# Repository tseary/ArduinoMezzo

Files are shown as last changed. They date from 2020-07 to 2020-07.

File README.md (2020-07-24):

# ArduinoMezzo
Arduino Mezzo is a functional half-scale replica of the Arduino Uno.<p/> 
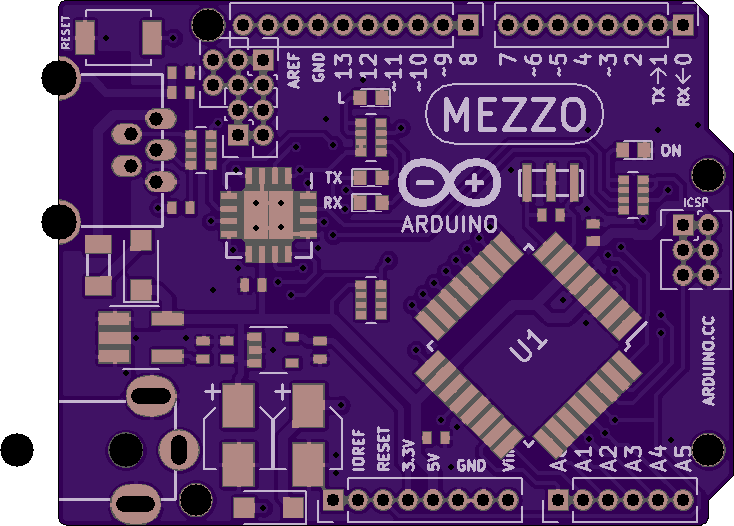
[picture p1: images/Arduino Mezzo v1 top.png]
My image
<p/>

I created this project as a novelty and as an exercise in miniaturization. As much as possible, the components
are 50% of the size of the components on the real Uno. The pin headers are all 50 mil pitch instead of 100 mil, and
the LEDs are 0402's instead of 0805's. Some parts differ because a half-scale version doesn't exist - the
USB connector is a mini-B instead of B type, and the power jack is has a 2.5 mm OD instead of the standard 5.5 mm.<p/>

Functional differences include a simplified power supply, and a different chip entirely for the USB-serial bridge.
The real Uno power supply has comparators and MOSFETs to select between USB and battery power. The Mezzo simply
combines the two sources using schottky diodes. To program the Mezzo, you have to manually press the reset button
since there is no DTR reset as in the Uno.<p/>

I hope that this project amuses you as much as it did me. If you make your own Mezzo I'd love to see it!<p/>

Disclaimer: This is not an official Arduino product and I am not affiliated with Arduino in any way.
This design is made available for anyone to use for any purpose, at their own risk.

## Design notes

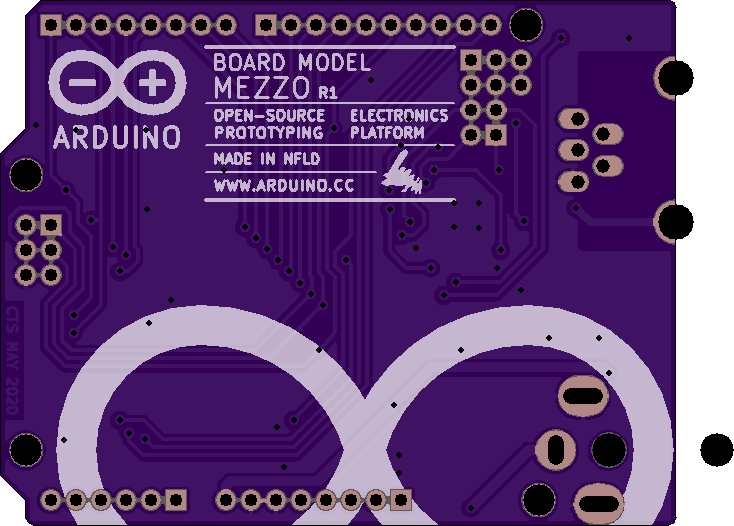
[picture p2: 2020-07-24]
images/Arduino Mezzo v1 bottom.png

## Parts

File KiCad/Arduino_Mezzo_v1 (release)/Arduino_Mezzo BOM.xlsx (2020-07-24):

Reference | Value | Footprint | Digikey Part # | In Cart | Datasheet
SW1 | RESET | Buttons_Switches_SMD:SW_SPST_B3U-1000P | SW1020CT-ND‎ | 3 | ~
C1 | 10uF | Capacitors_SMD:CP_Elec_3x5.3 | 338-1793-1-ND‎ | 6 | AVE106M16A12T-F
C2 | 10uF | Capacitors_SMD:CP_Elec_3x5.3 | 338-1793-1-ND‎ |  | AVE106M16A12T-F
F1 | 500mA | Custom_Library:0805 | 507-2075-1-ND‎ | 3 | 0ZCK0050AF2E
J6 | VIN | Custom_Library:Conn_DC_Jack_2.35mm_TH | 732-5920-ND‎ | 3 | ~
J5 | USB_B_Mini | Custom_Library:Conn_USB_Mini-B_TH | 54-00019T-ND‎ | 3 | 54-00019
H1 | 2020-01-16 | Custom_Library:M2_Isolated | N/A | 0 | ~
H2 | 2020-01-16 | Custom_Library:M2_Isolated | N/A |  | ~
H3 | 2020-01-16 | Custom_Library:M2_Isolated | N/A |  | ~
H4 | 2020-01-16 | Custom_Library:M2_Isolated | N/A |  | ~
Y1 | 16MHz | Custom_Library:XTAL_SMD_CSTNE | 490-17948-1-ND‎ | 3 | CSTNE16M0V530000R0
D1 | RB560VM | Diodes_SMD:D_SOD-323_HandSoldering | 1727-8169-1-ND‎ | 6 | ~
D8 | RB560VM | Diodes_SMD:D_SOD-323_HandSoldering | 1727-8169-1-ND‎ |  | ~
U2 | FT230XQ | Housings_DFN_QFN:QFN-16-1EP_4x4mm_Pitch0.65mm | 768-1130-1-ND‎ | 3 | https://www.ftdichip.com/Support/Documents/DataSheets/ICs/DS_FT230X.pdf
U1 | ATmega328P-AU | Housings_QFP:TQFP-32_7x7mm_Pitch0.8mm | ATMEGA328P-AU-ND | 3 | http://ww1.microchip.com/downloads/en/DeviceDoc/ATmega328_P%20AVR%20MCU%20with%20picoPower%20Technology%20Data%20Sheet%2040001984A.pdf
D5 | ON | LEDs:LED_0402 | 732-11992-1-ND‎ | 10 | ~
D7 | L | LEDs:LED_0402 | 732-11993-1-ND‎ | 10 | ~
D4 | RX | LEDs:LED_0402 | 732-11993-1-ND‎ |  | ~
D3 | TX | LEDs:LED_0402 | 732-11993-1-ND‎ |  | ~
J2 | AD | Pin_Headers:Pin_Header_Straight_1x06_Pitch1.27mm | S9008E-06-ND‎ | 3 | ~
J4 | IOL | Pin_Headers:Pin_Header_Straight_1x08_Pitch1.27mm | S9008E-08-ND‎ | 6 | ~
J1 | POWER | Pin_Headers:Pin_Header_Straight_1x08_Pitch1.27mm | S9008E-08-ND‎ |  | ~
J3 | IOH | Pin_Headers:Pin_Header_Straight_1x10_Pitch1.27mm | S9008E-10-ND‎ | 3 | ~
J9 | EXTRA | Pin_Headers:Pin_Header_Straight_2x02_Pitch1.27mm | N/A | 0 | ~
J8 | DUMMY | Pin_Headers:Pin_Header_Straight_2x03_Pitch1.27mm | S9015E-03-ND‎ | 6 | ~
J7 | ICSP | Pin_Headers:Pin_Header_Straight_2x03_Pitch1.27mm | S9015E-03-ND‎ |  | ~
C3 | 0.1uF | Resistors_SMD:R_0402_NoSilk | 732-7532-1-ND | 15 | ~
C4 | 0.1uF | Resistors_SMD:R_0402_NoSilk | 732-7532-1-ND |  | ~
C5 | 0.1uF | Resistors_SMD:R_0402_NoSilk | 732-7532-1-ND |  | ~
C6 | 0.1uF | Resistors_SMD:R_0402_NoSilk | 732-7532-1-ND |  | ~
R2 | 1M | Resistors_SMD:R_0402_NoSilk | RMCF0402FT1M00CT-ND | 10 | ~
C7 | 1uF | Resistors_SMD:R_0402_NoSilk | 399-4873-1-ND‎ | 10 | C0402C105K9PACTU
L1 | BLM21 | Resistors_SMD:R_0402_NoSilk | 445-2981-1-ND‎ | 3 | MPZ1005S121CT000
C8 | 470pF | Resistors_SMD:R_0402_NoSilk | 732-7554-1-ND‎ | 10 | ~
D2 | PGB1 | Resistors_SMD:R_0402_NoSilk | F2862CT-ND‎ | 6 | ~
D6 | PGB1 | Resistors_SMD:R_0402_NoSilk | F2862CT-ND‎ |  | ~
RN3 | 22 | Resistors_SMD:R_Array_Convex_4x0402 | 741X083220JPCT-ND | 3
RN1 | 10k | Resistors_SMD:R_Array_Convex_4x0402 | 741X083103JPCT-ND | 3
RN2 | 1k | Resistors_SMD:R_Array_Convex_4x0402 | 741X083102JPCT-ND | 6
RN4 | 1k | Resistors_SMD:R_Array_Convex_4x0402 | 741X083102JPCT-ND
U3 | MIC5219-5.0YM5 | TO_SOT_Packages_SMD:SOT-23-5_HandSoldering | 576-2770-1-ND‎ | 3 | http://ww1.microchip.com/downloads/en/DeviceDoc/MIC5219-500mA-Peak-Output-LDO-Regulator-DS20006021A.pdf
U4 | MIC5365-3.3YC5 | TO_SOT_Packages_SMD:SOT-353_SC-70-5 | 576-3193-1-ND‎ | 3 | http://ww1.microchip.com/downloads/en/DeviceDoc/mic5365.pdf

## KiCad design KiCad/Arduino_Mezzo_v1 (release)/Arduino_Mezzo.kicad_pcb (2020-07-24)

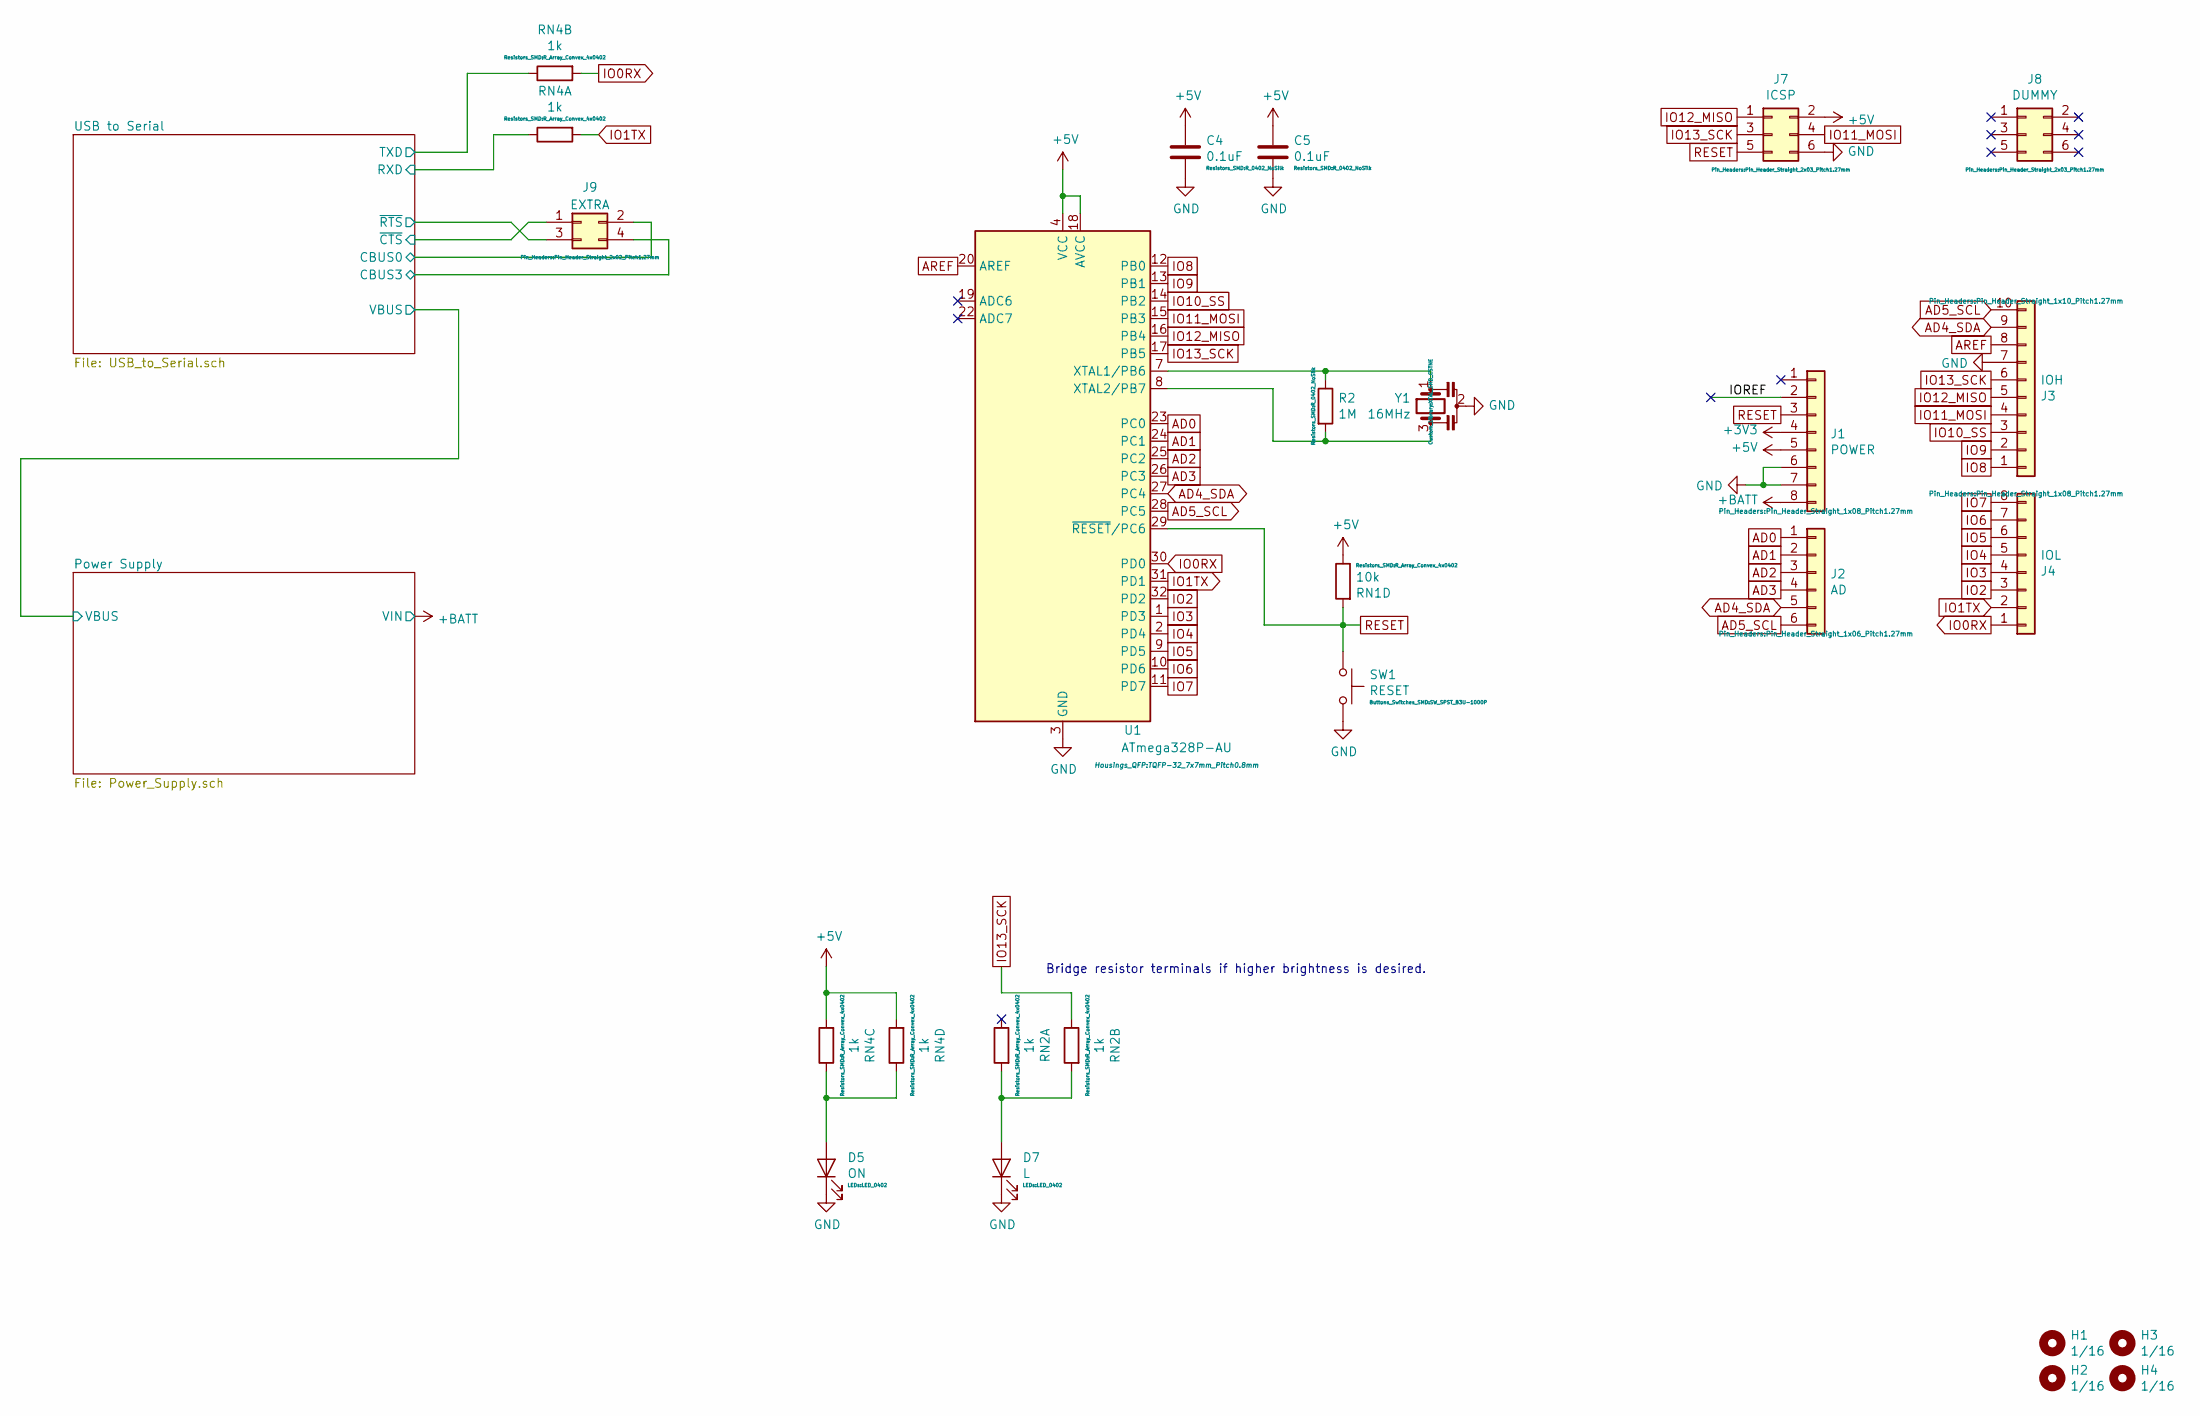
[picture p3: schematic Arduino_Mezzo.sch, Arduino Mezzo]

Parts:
C4, C5: 0.1uF; R_0402_NoSilk
D5: ON; LED_0402
D7: L; LED_0402
H1, H2, H3, H4: 1/16; M2_Isolated
J1: POWER; Pin_Header_Straight_1x08_Pitch1.27mm
J2: AD; Pin_Header_Straight_1x06_Pitch1.27mm
J3: IOH; Pin_Header_Straight_1x10_Pitch1.27mm
J4: IOL; Pin_Header_Straight_1x08_Pitch1.27mm
J7: ICSP; Pin_Header_Straight_2x03_Pitch1.27mm
J8: DUMMY; Pin_Header_Straight_2x03_Pitch1.27mm
J9: EXTRA; Pin_Header_Straight_2x02_Pitch1.27mm
R2: 1M; R_0402_NoSilk
RN1: 10k; R_Array_Convex_4x0402
RN2, RN4: 1k; R_Array_Convex_4x0402
SW1: RESET; SW_SPST_B3U-1000P
U1: ATmega328P-AU; TQFP-32_7x7mm_Pitch0.8mm
Y1: 16MHz; XTAL_SMD_CSTNE

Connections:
+3V3: J1.4; also elsewhere on the board
+5V: C4.1, C5.1, J1.5, J7.2, RN1.5, RN4.3, RN4.4, U1.4 (VCC), U1.6 (VCC), U1.18 (AVCC); also elsewhere on the board
+BATT: J1.8; also elsewhere on the board
/IOREF: J1.2
/USB to Serial/CBUS0: J9.2; also elsewhere on the board
/USB to Serial/CBUS3: J9.4; also elsewhere on the board
/USB to Serial/RXD: RN4.8; also elsewhere on the board
/USB to Serial/TXD: RN4.7; also elsewhere on the board
/USB to Serial/~CTS: J9.1; also elsewhere on the board
/USB to Serial/~RTS: J9.3; also elsewhere on the board
AD0: J2.1, U1.23 (PC0)
AD1: J2.2, U1.24 (PC1)
AD2: J2.3, U1.25 (PC2)
AD3: J2.4, U1.26 (PC3)
AD4_SDA: J2.5, J3.9, U1.27 (PC4)
AD5_SCL: J2.6, J3.10, U1.28 (PC5)
AREF: J3.8, U1.20 (AREF)
GND: C4.2, C5.2, D5.1 (K), D7.1 (K), J1.6, J1.7, J3.7, J7.6, SW1.2, U1.3 (GND), U1.5 (GND), U1.21 (GND), Y1.2; also elsewhere on the board
IO0RX: J4.1, RN4.2, U1.30 (PD0)
IO1TX: J4.2, RN4.1, U1.31 (PD1)
IO2: J4.3, U1.32 (PD2)
IO3: J4.4, U1.1 (PD3)
IO4: J4.5, U1.2 (PD4)
IO5: J4.6, U1.9 (PD5)
IO6: J4.7, U1.10 (PD6)
IO7: J4.8, U1.11 (PD7)
IO8: J3.1, U1.12 (PB0)
IO9: J3.2, U1.13 (PB1)
IO10_SS: J3.3, U1.14 (PB2)
IO11_MOSI: J3.4, J7.4, U1.15 (PB3)
IO12_MISO: J3.5, J7.1, U1.16 (PB4)
IO13_SCK: J3.6, J7.3, RN2.7, U1.17 (PB5)
unnamed: D5.2 (A), RN4.5, RN4.6
unnamed: D7.2 (A), RN2.1, RN2.2
unnamed: R2.1, U1.7 (XTAL1/PB6), Y1.1
unnamed: R2.2, U1.8 (XTAL2/PB7), Y1.3
RESET: J1.3, J7.5, RN1.4, SW1.1, U1.29 (~RESET~/PC6)

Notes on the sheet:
Bridge resistor terminals if higher brightness is desired.

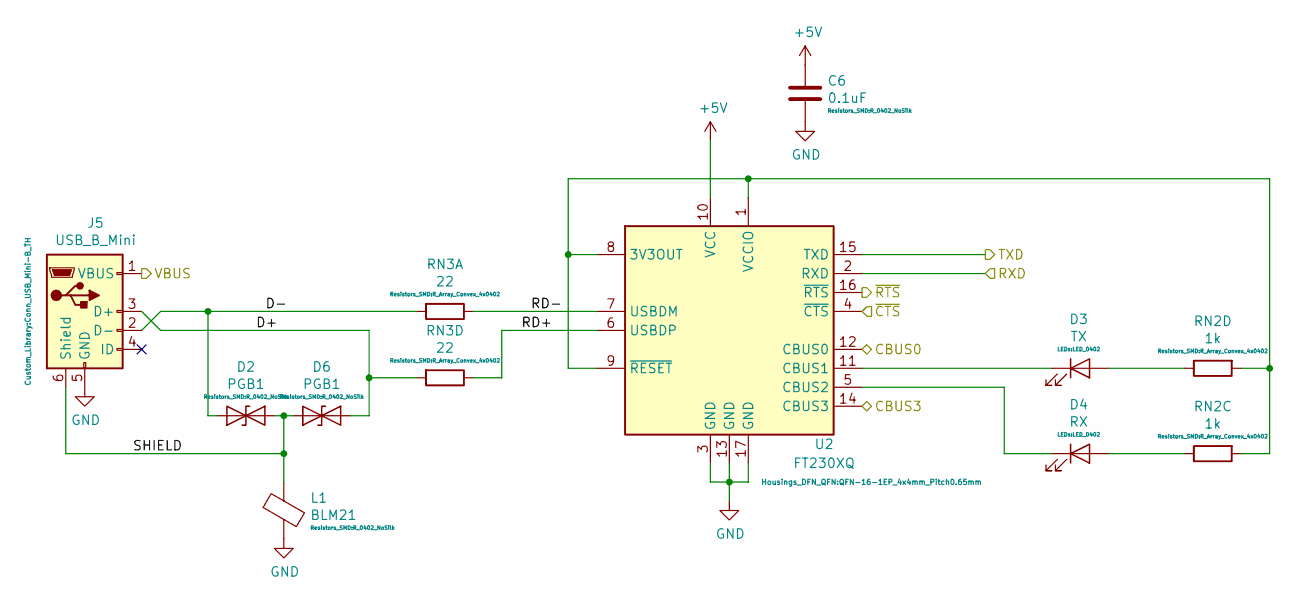
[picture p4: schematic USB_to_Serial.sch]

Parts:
C6: 0.1uF; R_0402_NoSilk
D2, D6: PGB1; R_0402_NoSilk
D3: TX; LED_0402
D4: RX; LED_0402
J5: USB_B_Mini; Conn_USB_Mini-B_TH
L1: BLM21; R_0402_NoSilk
RN2: 1k; R_Array_Convex_4x0402
RN3: 22; R_Array_Convex_4x0402
U2: FT230XQ; QFN-16-1EP_4x4mm_Pitch0.65mm

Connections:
+5V: C6.1, U2.10 (VCC); also elsewhere on the board
/Power Supply/VBUS: J5.1 (VBUS); also elsewhere on the board
/USB to Serial/CBUS0: U2.12 (CBUS0); also elsewhere on the board
/USB to Serial/CBUS3: U2.14 (CBUS3); also elsewhere on the board
/USB to Serial/D+: D6.2 (A2), J5.3 (D+), RN3.4
/USB to Serial/D-: D2.1 (A1), J5.2 (D-), RN3.1
/USB to Serial/RD+: RN3.5, U2.6 (USBDP)
/USB to Serial/RD-: RN3.8, U2.7 (USBDM)
/USB to Serial/RXD: U2.2 (RXD); also elsewhere on the board
/USB to Serial/SHIELD: D2.2 (A2), D6.1 (A1), J5.6 (Shield), L1.1
/USB to Serial/TXD: U2.15 (TXD); also elsewhere on the board
/USB to Serial/~CTS: U2.4 (~CTS); also elsewhere on the board
/USB to Serial/~RTS: U2.16 (~RTS); also elsewhere on the board
GND: C6.2, J5.5 (GND), L1.2, U2.3 (GND), U2.13 (GND), U2.17 (GND); also elsewhere on the board
unnamed: D3.1 (K), U2.11 (CBUS1)
unnamed: D3.2 (A), RN2.5
unnamed: D4.1 (K), U2.5 (CBUS2)
unnamed: D4.2 (A), RN2.6
unnamed: RN2.3, RN2.4, U2.1 (VCCIO), U2.8 (3V3OUT), U2.9 (~RESET)

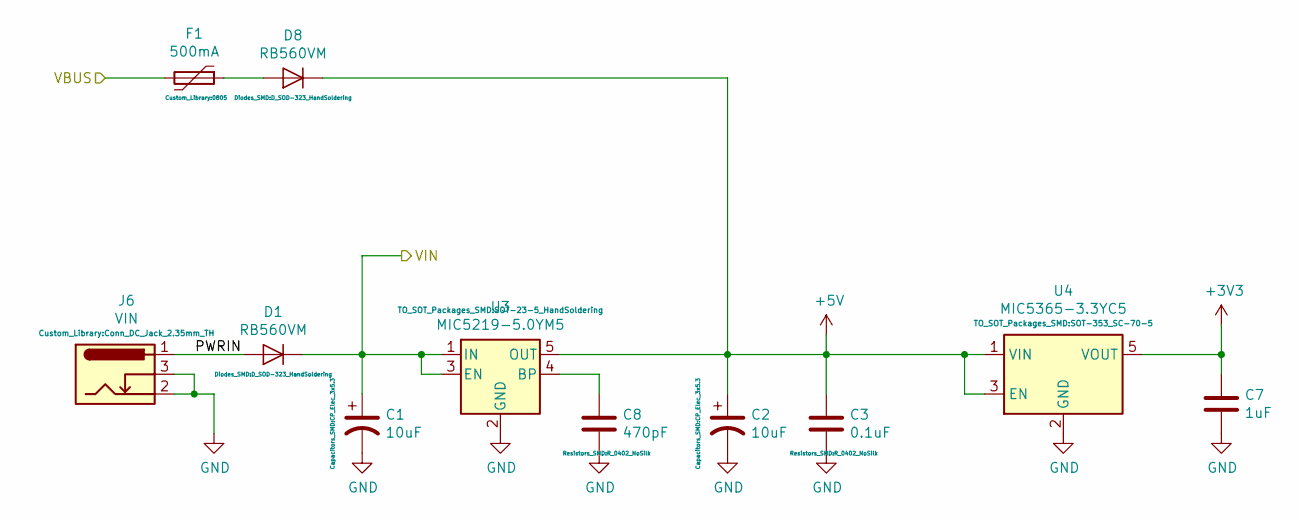
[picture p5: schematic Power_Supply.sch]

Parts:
C1, C2: 10uF; CP_Elec_3x5.3
C3: 0.1uF; R_0402_NoSilk
C7: 1uF; R_0402_NoSilk
C8: 470pF; R_0402_NoSilk
D1, D8: RB560VM; D_SOD-323_HandSoldering
F1: 500mA; 0805
J6: VIN; Conn_DC_Jack_2.35mm_TH
U3: MIC5219-5.0YM5; SOT-23-5_HandSoldering
U4: MIC5365-3.3YC5; SOT-353_SC-70-5

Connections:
+3V3: C7.1, U4.5 (VOUT); also elsewhere on the board
+5V: C2.1, C3.1, D8.1 (K), U3.5 (OUT), U4.1 (VIN), U4.3 (EN); also elsewhere on the board
+BATT: C1.1, D1.1 (K), U3.1 (IN), U3.3 (EN); also elsewhere on the board
/Power Supply/PWRIN: D1.2 (A), J6.1
/Power Supply/VBUS: F1.2; also elsewhere on the board
GND: C1.2, C2.2, C3.2, C7.2, C8.2, J6.2, J6.3, U3.2 (GND), U4.2 (GND); also elsewhere on the board
unnamed: C8.1, U3.4 (BP)
unnamed: D8.2 (A), F1.1

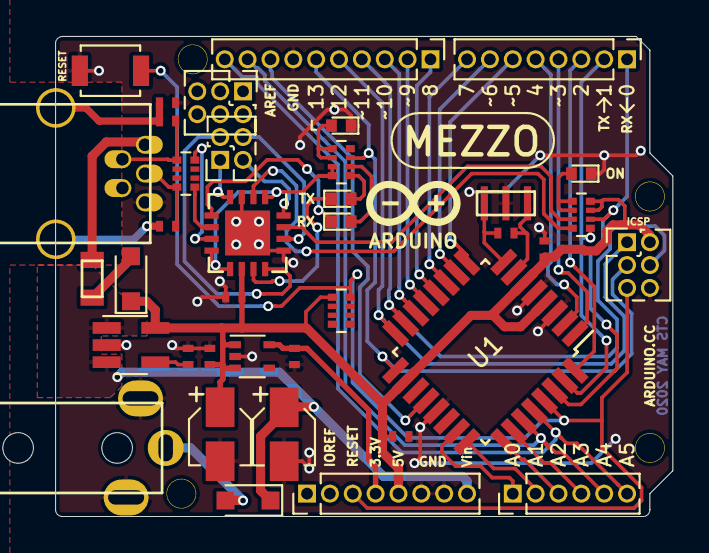
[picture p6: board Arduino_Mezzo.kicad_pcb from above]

Board: 2 copper layers, 34.3 x 26.7 mm, 42 parts (0 on the bottom side), 50 nets.
